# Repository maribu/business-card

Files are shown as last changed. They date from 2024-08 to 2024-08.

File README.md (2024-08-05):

# Marian's Business Card

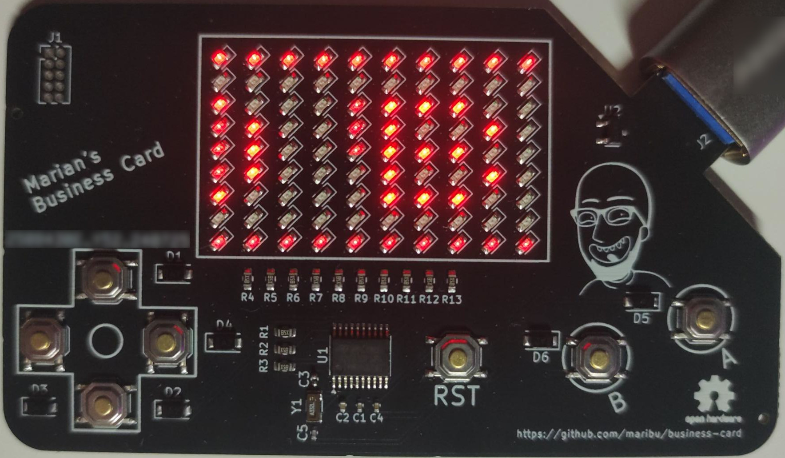
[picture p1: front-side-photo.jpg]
photo of the front side of the PCB

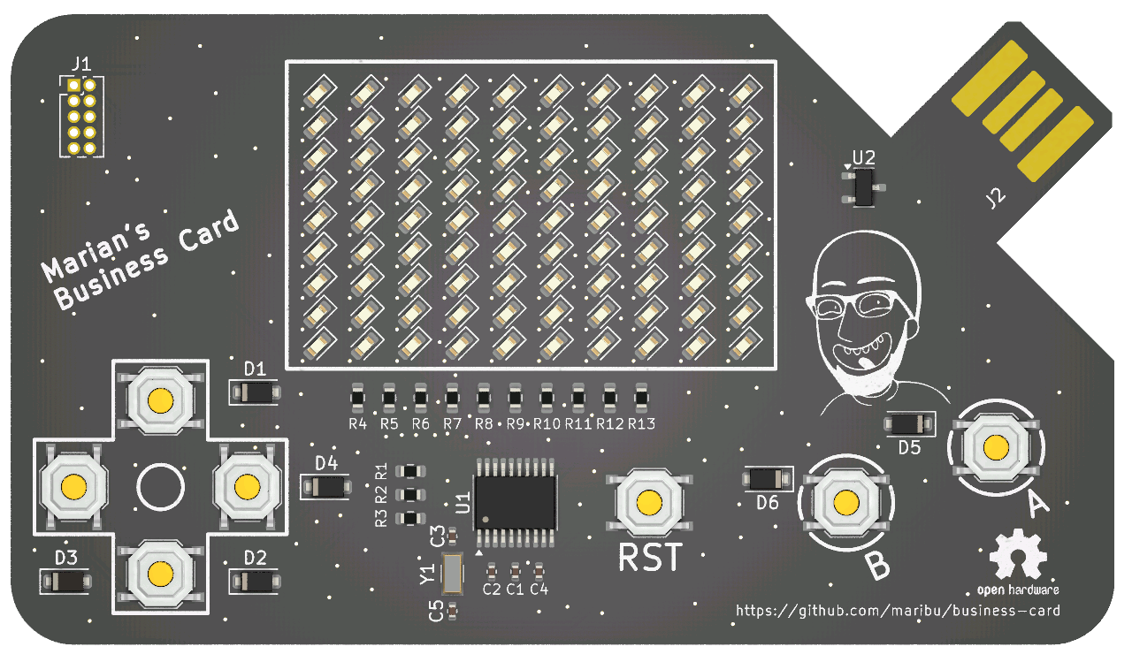
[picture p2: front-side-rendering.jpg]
rendering of the front side of the PCB


This repository contains an open hardware business card running open source
software.

## Getting started

### Hardware

Using KiCad, add Silkscreen details such as your name. E.g. I added my contact
details and word cloud of my skills on the back of the PCB. Using the JLCPCB
fabrication plugin of KiCAD, you can export the production files to directly
order the PCBs.

Note that when using vanilla PCB options (1.6 mm PCB thickness, HASL surface
finish) the USB connector will be a tad too thin to perfectly make contact with
a USB socket. Ideally you would use 2.0 mm PCB thickness and ENIG surface
finish, but that would be so expensive that it defeats the purpose of a
business card. Instead, you can just add a bit of solder on the USB contacts to
increase the thickness.

### Software

A simple "hello world" demo is given in
`software/RIOT-based-apps/apps/hello-world` that you can flash using e.g. a
J-Link EDU Mini programmer. Rather than using a cable, just plug the pins of
the J-Link EDU Mini programmer from the underside through the holes and rotate
the programmer until the pins and holes have contact. In addition, you need to
power the board (ideally via a USB-A extension cord).

With the programmer connected and the board powered, simply run:

    make flash

Refer to the [RIOT documentation](https://doc.riot-os.org/) for more details on
the software.

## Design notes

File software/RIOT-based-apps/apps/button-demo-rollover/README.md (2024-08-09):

# Button Rollover Demo

The use of Charlieplexing for has the disadvantage that when more than one
button is pressed at the same time, it may be impossible to reliably determine
which set of buttons is pressed.

E.g. the up button is detected when current can flow from `BUTTON_MATRIX_PIN_0`
to `BUTTON_MATRIX_PIN_2`, the right button is detected when current can flow
from `BUTTON_MATRIX_PIN_2` to `BUTTON_MATRIX_PIN_1`, and the left button is
detected when current can flow from `BUTTON_MATRIX_PIN_0` to
`BUTTON_MATRIX_PIN_1`. If now both the up and the right button are pressed,
current can flow from `BUTTON_MATRIX_PIN_0` to `BUTTON_MATRIX_PIN_2` (via the
closed up button) and from `BUTTON_MATRIX_PIN_2` to `BUTTON_MATRIX_PIN_1` (via
the closed right button). Hence, current can also flow from pin 0 to pin 1 (via
pin 2), regardless of whether the left button is pressed or not.

The board provides the `compensate_rollover()` function that can help here:
Under the assumption that at most two buttons are pressed at the same time,
when registering three pressed buttons the ghost key can be reliably determined.

This app showcases this by displaying the raw button input at the top of
the screen and the compensated one at the bottom. Note that when pressing
three buttons at the same time, this simple heuristic is not sufficient.

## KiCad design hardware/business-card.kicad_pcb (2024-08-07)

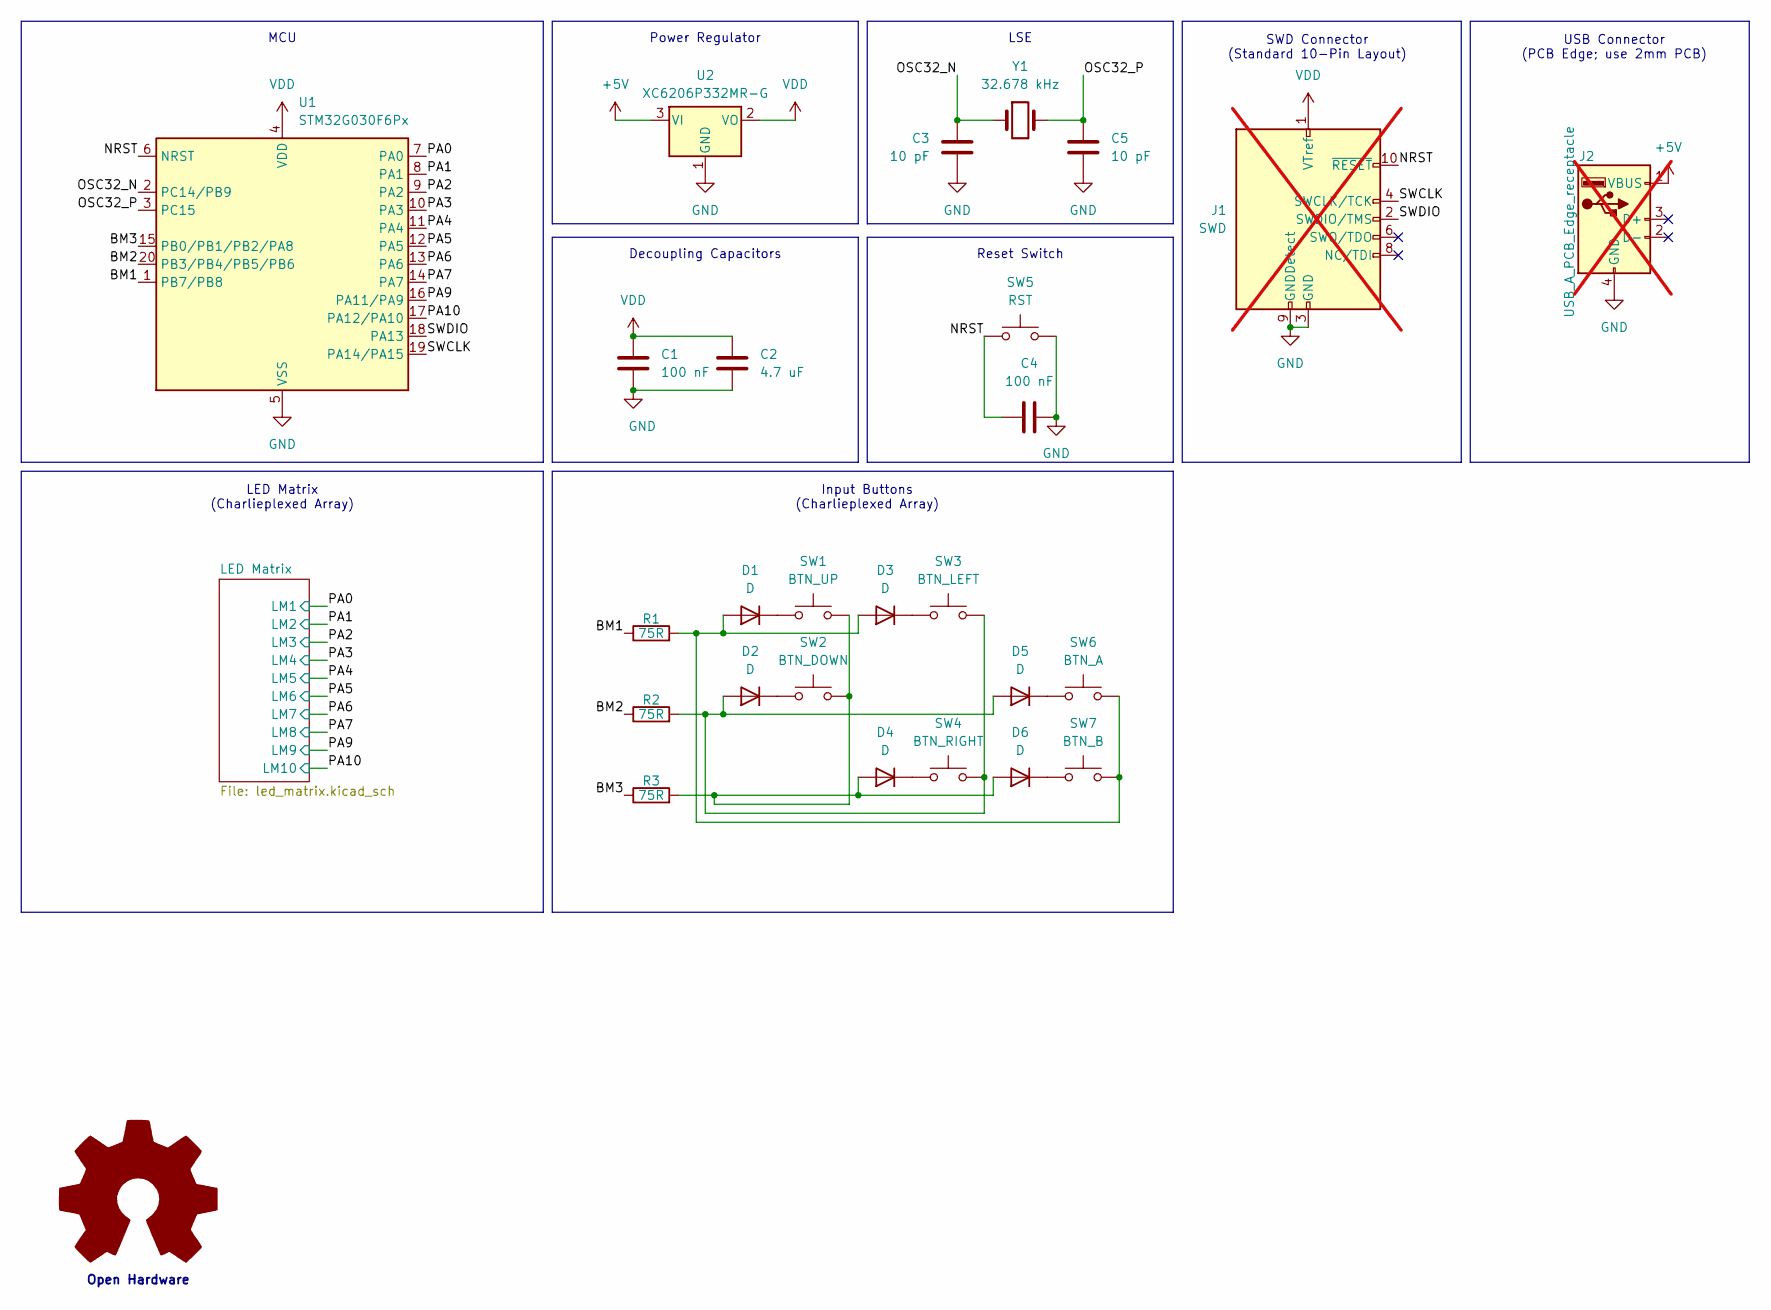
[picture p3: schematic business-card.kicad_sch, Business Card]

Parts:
C1, C4: 100 nF; C_0402_1005Metric; MPN C1525
C2: 4.7 uF; C_0402_1005Metric; MPN C23733
C3, C5: 10 pF; C_0402_1005Metric; MPN C32949
D1, D2, D3, D4, D5, D6: D; D_SOD-123F; MPN C64898
J1: SWD; PinHeader_2x05_P1.27mm_Vertical; not fitted
J2: USB_A_PCB_Edge_receptacle; not fitted
R1, R2, R3: 75R; R_0603_1608Metric; MPN C4275
SW1: BTN_UP; SW_Push_1P1T_XKB_TS-1187A; MPN C318884
SW2: BTN_DOWN; SW_Push_1P1T_XKB_TS-1187A; MPN C318884
SW3: BTN_LEFT; SW_Push_1P1T_XKB_TS-1187A; MPN C318884
SW4: BTN_RIGHT; SW_Push_1P1T_XKB_TS-1187A; MPN C318884
SW5: RST; SW_Push_1P1T_XKB_TS-1187A; MPN C318884
SW6: BTN_A; SW_Push_1P1T_XKB_TS-1187A; MPN C318884
SW7: BTN_B; SW_Push_1P1T_XKB_TS-1187A; MPN C318884
U1: STM32G030F6Px; TSSOP-20_4.4x6.5mm_P0.65mm; MPN C529330
U2: XC6206P332MR-G; SOT-23-3; MPN C5446
Y1: 32.678 kHz; Crystal_SMD_3215-2Pin_3.2x1.5mm; MPN C32346

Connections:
+5V: J2.1 (VBUS), U2.3 (VI)
/BM1: R1.1, U1.1 (PB7/PB8)
/BM2: R2.1, U1.20 (PB3/PB4/PB5/PB6)
/BM3: R3.1, U1.15 (PB0/PB1/PB2/PA8)
/NRST: C4.1, J1.10 (~RESET), SW5.1, U1.6 (NRST)
/OSC32_N: C3.1, U1.2 (PC14/PB9), Y1.1
/OSC32_P: C5.1, U1.3 (PC15), Y1.2
/PA0: U1.7 (PA0); also elsewhere on the board
/PA1: U1.8 (PA1); also elsewhere on the board
/PA2: U1.9 (PA2); also elsewhere on the board
/PA3: U1.10 (PA3); also elsewhere on the board
/PA4: U1.11 (PA4); also elsewhere on the board
/PA5: U1.12 (PA5); also elsewhere on the board
/PA6: U1.13 (PA6); also elsewhere on the board
/PA7: U1.14 (PA7); also elsewhere on the board
/PA9: U1.16 (PA11/PA9); also elsewhere on the board
/PA10: U1.17 (PA12/PA10); also elsewhere on the board
/SWCLK: J1.4 (SWCLK/TCK), U1.19 (PA14/PA15)
/SWDIO: J1.2 (SWDIO/TMS), U1.18 (PA13)
GND: C1.2, C2.2, C3.2, C4.2, C5.2, J1.3 (GND), J1.5 (GND), J1.9 (GNDDetect), J2.4 (GND), SW5.2, U1.5 (VSS), U2.1 (GND)
unnamed: D1.2 (A), D3.2 (A), R1.2, SW6.2, SW7.2
unnamed: D1.1 (K), SW1.1
unnamed: D2.2 (A), D5.2 (A), R2.2, SW3.2, SW4.2
unnamed: D2.1 (K), SW2.1
unnamed: D3.1 (K), SW3.1
unnamed: D4.2 (A), D6.2 (A), R3.2, SW1.2, SW2.2
unnamed: D4.1 (K), SW4.1
unnamed: D5.1 (K), SW6.1
unnamed: D6.1 (K), SW7.1
VDD: C1.1, C2.1, J1.1 (VTref), U1.4 (VDD), U2.2 (VO)

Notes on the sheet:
Input Buttons (Charlieplexed Array)
SWD Connector (Standard 10-Pin Layout)
MCU
Reset Switch
Power Regulator
LSE
Decoupling Capacitors
USB Connector (PCB Edge; use 2mm PCB)
LED Matrix (Charlieplexed Array)
Open Hardware

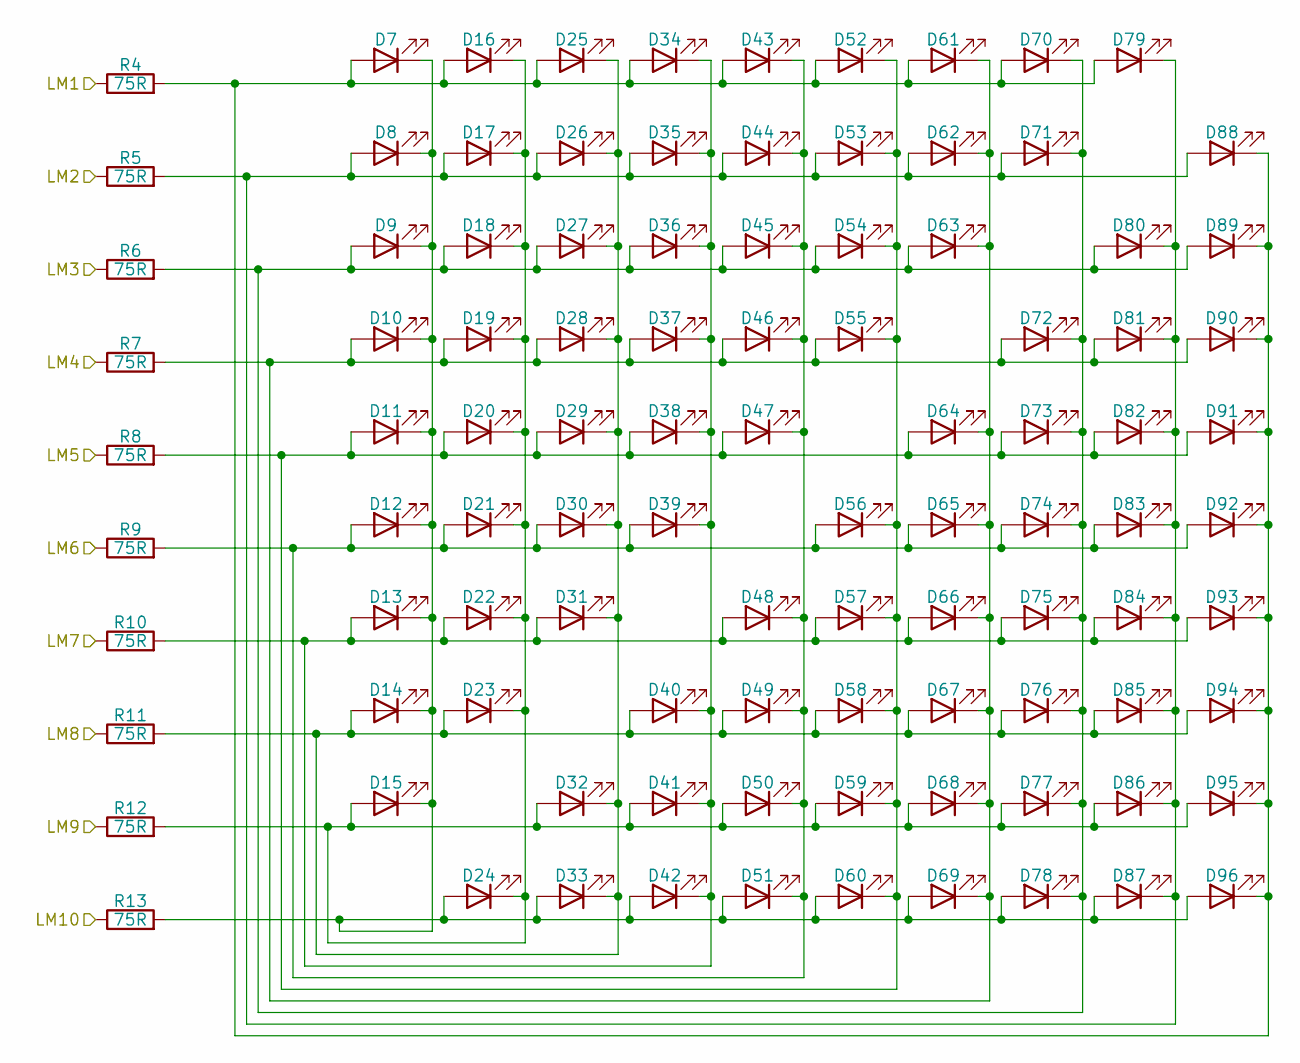
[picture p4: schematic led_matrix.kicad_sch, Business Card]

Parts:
D7, D8, D9, D10, D11, D12, D13, D14, D15, D16, D17, D18, D19, D20, D21, D22, D23, D24, D25, D26, D27, D28, D29, D30, D31, D32, D33, D34, D35, D36, D37, D38, D39, D40, D41, D42, D43, D44, D45, D46, D47, D48, D49, D50, D51, D52, D53, D54, D55, D56, D57, D58, D59, D60, D61, D62, D63, D64, D65, D66, D67, D68, D69, D70, D71, D72, D73, D74, D75, D76, D77, D78, D79, D80, D81, D82, D83, D84, D85, D86, D87, D88, D89, D90, D91, D92, D93, D94, D95, D96: LED; LED_0603_1608Metric; LCSC C2286
R4, R5, R6, R7, R8, R9, R10, R11, R12, R13: 75R; R_0603_1608Metric; LCSC C4275

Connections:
/PA0: R4.1; also elsewhere on the board
/PA1: R5.1; also elsewhere on the board
/PA2: R6.1; also elsewhere on the board
/PA3: R7.1; also elsewhere on the board
/PA4: R8.1; also elsewhere on the board
/PA5: R9.1; also elsewhere on the board
/PA6: R10.1; also elsewhere on the board
/PA7: R11.1; also elsewhere on the board
/PA9: R12.1; also elsewhere on the board
/PA10: R13.1; also elsewhere on the board
unnamed: D10.2 (A), D19.2 (A), D28.2 (A), D37.2 (A), D46.2 (A), D55.2 (A), D61.1 (K), D62.1 (K), D63.1 (K), D64.1 (K), D65.1 (K), D66.1 (K), D67.1 (K), D68.1 (K), D69.1 (K), D72.2 (A), D81.2 (A), D90.2 (A), R7.2
unnamed: D7.1 (K), D8.1 (K), D9.1 (K), D10.1 (K), D11.1 (K), D12.1 (K), D13.1 (K), D14.1 (K), D15.1 (K), D24.2 (A), D33.2 (A), D42.2 (A), D51.2 (A), D60.2 (A), D69.2 (A), D78.2 (A), D87.2 (A), D96.2 (A), R13.2
unnamed: D11.2 (A), D20.2 (A), D29.2 (A), D38.2 (A), D47.2 (A), D52.1 (K), D53.1 (K), D54.1 (K), D55.1 (K), D56.1 (K), D57.1 (K), D58.1 (K), D59.1 (K), D60.1 (K), D64.2 (A), D73.2 (A), D82.2 (A), D91.2 (A), R8.2
unnamed: D12.2 (A), D21.2 (A), D30.2 (A), D39.2 (A), D43.1 (K), D44.1 (K), D45.1 (K), D46.1 (K), D47.1 (K), D48.1 (K), D49.1 (K), D50.1 (K), D51.1 (K), D56.2 (A), D65.2 (A), D74.2 (A), D83.2 (A), D92.2 (A), R9.2
unnamed: D13.2 (A), D22.2 (A), D31.2 (A), D34.1 (K), D35.1 (K), D36.1 (K), D37.1 (K), D38.1 (K), D39.1 (K), D40.1 (K), D41.1 (K), D42.1 (K), D48.2 (A), D57.2 (A), D66.2 (A), D75.2 (A), D84.2 (A), D93.2 (A), R10.2
unnamed: D14.2 (A), D23.2 (A), D25.1 (K), D26.1 (K), D27.1 (K), D28.1 (K), D29.1 (K), D30.1 (K), D31.1 (K), D32.1 (K), D33.1 (K), D40.2 (A), D49.2 (A), D58.2 (A), D67.2 (A), D76.2 (A), D85.2 (A), D94.2 (A), R11.2
unnamed: D15.2 (A), D16.1 (K), D17.1 (K), D18.1 (K), D19.1 (K), D20.1 (K), D21.1 (K), D22.1 (K), D23.1 (K), D24.1 (K), D32.2 (A), D41.2 (A), D50.2 (A), D59.2 (A), D68.2 (A), D77.2 (A), D86.2 (A), D95.2 (A), R12.2
unnamed: D7.2 (A), D16.2 (A), D25.2 (A), D34.2 (A), D43.2 (A), D52.2 (A), D61.2 (A), D70.2 (A), D79.2 (A), D88.1 (K), D89.1 (K), D90.1 (K), D91.1 (K), D92.1 (K), D93.1 (K), D94.1 (K), D95.1 (K), D96.1 (K), R4.2
unnamed: D8.2 (A), D17.2 (A), D26.2 (A), D35.2 (A), D44.2 (A), D53.2 (A), D62.2 (A), D71.2 (A), D79.1 (K), D80.1 (K), D81.1 (K), D82.1 (K), D83.1 (K), D84.1 (K), D85.1 (K), D86.1 (K), D87.1 (K), D88.2 (A), R5.2
unnamed: D9.2 (A), D18.2 (A), D27.2 (A), D36.2 (A), D45.2 (A), D54.2 (A), D63.2 (A), D70.1 (K), D71.1 (K), D72.1 (K), D73.1 (K), D74.1 (K), D75.1 (K), D76.1 (K), D77.1 (K), D78.1 (K), D80.2 (A), D89.2 (A), R6.2

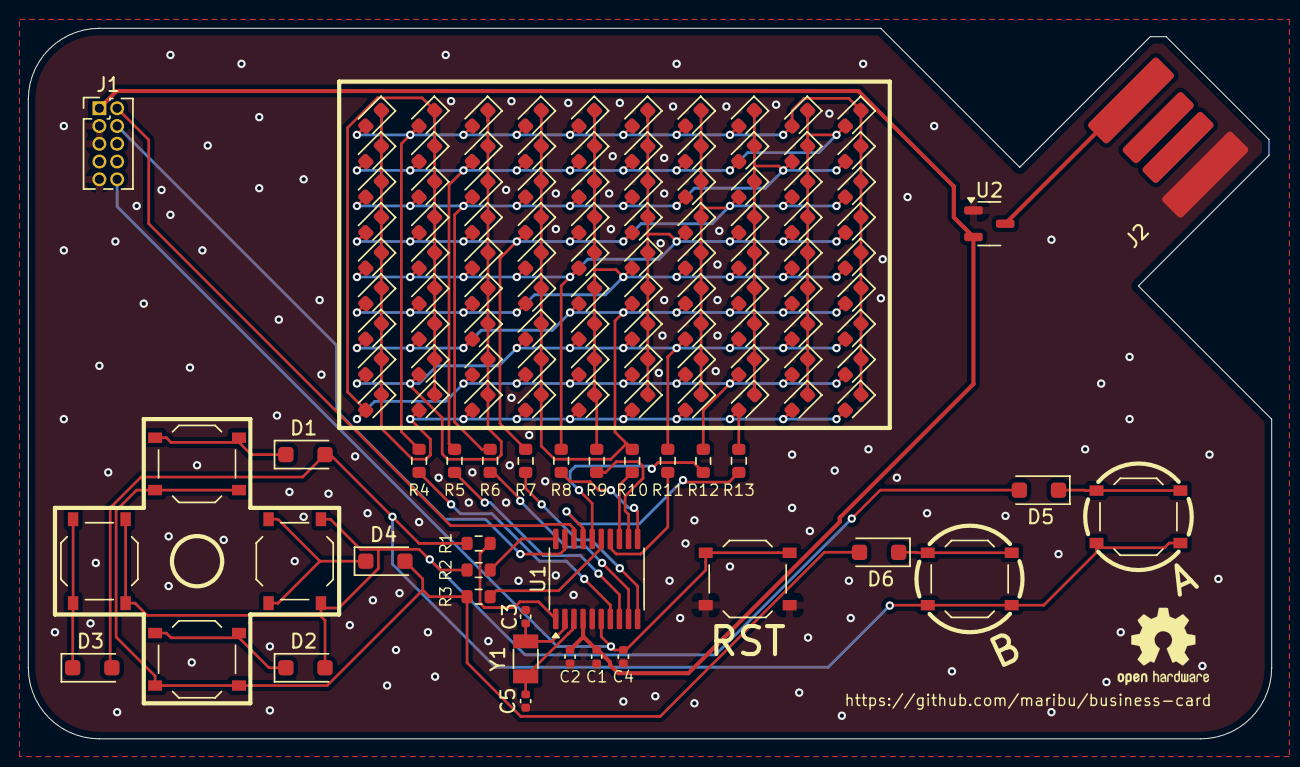
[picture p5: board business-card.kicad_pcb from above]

Board: 2 copper layers, 88.9 x 50.8 mm, 127 parts (0 on the bottom side), 40 nets.

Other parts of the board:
G**: OSHW-Logo2_7.3x6mm_SilkScreen

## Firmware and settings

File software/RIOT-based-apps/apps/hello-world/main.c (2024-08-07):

/*
 * Copyright (C) 2014 Freie Universität Berlin
 *
 * This file is subject to the terms and conditions of the GNU Lesser
 * General Public License v2.1. See the file LICENSE in the top level
 * directory for more details.
 */

/**
 * @ingroup     examples
 * @{
 *
 * @file
 * @brief       Hello World application
 *
 * @author      Kaspar Schleiser <kaspar@schleiser.de>
 * @author      Ludwig Knüpfer <ludwig.knuepfer@fu-berlin.de>
 *
 * @}
 */

#include <stdio.h>

#include "led_matrix.h"

int main(void)
{
    puts("Hello World!");

    printf("You are running RIOT on a(n) %s board.\n", RIOT_BOARD);
    printf("This board features a(n) %s CPU.\n", RIOT_CPU);

    const uint32_t frames_per_level = 2;
    uint32_t frame_target = led_matrix_frame_number() + frames_per_level;

    led_matrix_fb_clear();
    for (;;) {
        const char *text = "IoT";
        const size_t len = 3;

        for (uint8_t b = 1; b < LED_MATRIX_BRIGHTNESS_LEVELS; b++) {
            led_matrix_text(&bitmap_font_matrix_light8, text, len, 1, 1, b);
            frame_target = led_matrix_fb_switch(frame_target) + frames_per_level;
        }

        for (uint8_t b = LED_MATRIX_BRIGHTNESS_MAX; b > 0; b--) {
            led_matrix_text(&bitmap_font_matrix_light8, text, len, 1, 1, b);
            frame_target = led_matrix_fb_switch(frame_target) + frames_per_level;
        }
    }

    return 0;
}

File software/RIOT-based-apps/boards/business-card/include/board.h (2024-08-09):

/*
 * Copyright (C) 2024 Marian Buschsieweke
 *
 * This file is subject to the terms and conditions of the GNU Lesser
 * General Public License v2.1. See the file LICENSE in the top level
 * directory for more details.
 */

/**
 * @ingroup     boards_business_card
 * @{
 *
 * @file
 * @brief       Board specific definitions for Marian's Business Card
 *
 * @author      Marian Buschsieweke <marian.buschsieweke@posteo.net>
 */

#ifndef BOARD_H
#define BOARD_H

#include "cpu.h"
#include "periph_conf.h"
#include "periph_cpu.h"

#ifdef __cplusplus
extern "C" {
#endif

/**
 * @name Charlieplexed LED Matrix GPIOs
 * @{
 */
#define LED_MATRIX_TIMER        TIMER_DEV(0)    /**< Timer to use for updating the LED matrix */
#define LED_MATRIX_PORT         GPIO_PORT_A     /**< The GPIO port the LED matrix connected to */

#define LED_MATRIX_PIN_0        0               /**< GPIO pin number connected to LED matrix 0 */
#define LED_MATRIX_PIN_1        1               /**< GPIO pin number connected to LED matrix 1 */
#define LED_MATRIX_PIN_2        2               /**< GPIO pin number connected to LED matrix 2 */
#define LED_MATRIX_PIN_3        3               /**< GPIO pin number connected to LED matrix 3 */
#define LED_MATRIX_PIN_4        4               /**< GPIO pin number connected to LED matrix 4 */
#define LED_MATRIX_PIN_5        5               /**< GPIO pin number connected to LED matrix 5 */
#define LED_MATRIX_PIN_6        6               /**< GPIO pin number connected to LED matrix 6 */
#define LED_MATRIX_PIN_7        7               /**< GPIO pin number connected to LED matrix 7 */
#define LED_MATRIX_PIN_8        11              /**< GPIO pin number connected to LED matrix 8 */
#define LED_MATRIX_PIN_9        12              /**< GPIO pin number connected to LED matrix 9 */
/** @} */

/**
 * @name Charlieplexed Button Matrix GPIOs
 * @{
 */
#define BUTTON_MATRIX_PORT              GPIO_PORT_B     /**< The GPIO port the button matrix connected to */

#define BUTTON_MATRIX_PIN_0             7               /**< GPIO pin number of button matrix pin 0 */
#define BUTTON_MATRIX_PIN_1             4               /**< GPIO pin number of button matrix pin 1 */
#define BUTTON_MATRIX_PIN_2             0               /**< GPIO pin number of button matrix pin 2 */

/* for button_matrix_test() */
#define BUTTON_MATRIX_COORD_UP          0,0     /**< Button matrix coordinates of the up button */
#define BUTTON_MATRIX_COORD_DOWN        0,1     /**< Button matrix coordinates of the up button */
#define BUTTON_MATRIX_COORD_LEFT        1,0     /**< Button matrix coordinates of the left button */
#define BUTTON_MATRIX_COORD_RIGHT       1,2     /**< Button matrix coordinates of the right button */
#define BUTTON_MATRIX_COORD_A           2,1     /**< Button matrix coordinates of the "A" button */
#define BUTTON_MATRIX_COORD_B           2,2     /**< Button matrix coordinates of the "B" button */

/* for button_matrix_scan() */
#define BUTTON_UP       0x01    /**< Bitmask to check for the up button */
#define BUTTON_LEFT     0x02    /**< Bitmask to check for the left button */
#define BUTTON_DOWN     0x04    /**< Bitmask to check for the down button */
#define BUTTON_A        0x08    /**< Bitmask to check for the "A" button */
#define BUTTON_RIGHT    0x10    /**< Bitmask to check for the right button */
#define BUTTON_B        0x20    /**< Bitmask to check for the "B" button */

/**
 * @brief   Heuristic to filter out fake inputs due to rollover
 *
 * The currently implemented heuristic assumes that at most two buttons are
 * pressed at the same time. E.g. pressing both up and right button will
 * result in a ghost reading for button left. So when up, right, and left
 * are enabled, it will assume that in fact only up and right are pressed
 * and left is a ghost input, which is trimmed.
 *
 * As long as indeed only two buttons are pressed at the same time, this
 * simple heuristic is sufficient. More sophisticated heuristics are
 * certainly possible that e.g. track the state over time. But
 * 2-key-rollover seems to be good enough for most games.
 *
 * @param[in]   scan    The output of button_matrix_scan()
 * @returl  The bitmask without rollover artifacts
 */
uint8_t compensate_rollover(uint8_t scan);
/** @} */

#ifdef __cplusplus
}
#endif

#endif /* BOARD_H */
/** @} */

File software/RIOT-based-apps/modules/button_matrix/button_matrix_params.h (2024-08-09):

/*
 * Copyright (C) 2024 Marian Buschsieweke
 *
 * This file is subject to the terms and conditions of the GNU Lesser
 * General Public License v2.1. See the file LICENSE in the top level
 * directory for more details.
 */

/**
 * @ingroup     drivers_button_matrix
 * @{
 *
 * @file
 * @brief       Hardware parameters of the button matrix
 *
 * @author      Marian Buschsieweke <marian.buschsieweke@posteo.net>
 */

#ifndef BUTTON_MATRIX_PARAMS_H
#define BUTTON_MATRIX_PARAMS_H

#include "board.h"

#ifdef __cplusplus
extern "C" {
#endif

#ifndef BUTTON_MATRIX_PORT
#  error "BUTTON_MATRIX_PORT not defined"
#endif

/**
 * @brief   Pin numbers of the button matrix
 */
static const uint8_t button_matrix_pins[] = {
    BUTTON_MATRIX_PIN_0,
    BUTTON_MATRIX_PIN_1,
#ifdef BUTTON_MATRIX_PIN_2
    BUTTON_MATRIX_PIN_2,
#endif
#ifdef BUTTON_MATRIX_PIN_3
    BUTTON_MATRIX_PIN_3,
#endif
#ifdef BUTTON_MATRIX_PIN_4
    BUTTON_MATRIX_PIN_4,
#endif
#ifdef BUTTON_MATRIX_PIN_5
    BUTTON_MATRIX_PIN_5,
#endif
#ifdef BUTTON_MATRIX_PIN_6
    BUTTON_MATRIX_PIN_6,
#endif
#ifdef BUTTON_MATRIX_PIN_7
    BUTTON_MATRIX_PIN_7,
#endif
#ifdef BUTTON_MATRIX_PIN_8
    BUTTON_MATRIX_PIN_8,
#endif
#ifdef BUTTON_MATRIX_PIN_9
    BUTTON_MATRIX_PIN_9,
#endif
#ifdef BUTTON_MATRIX_PIN_10
    BUTTON_MATRIX_PIN_10,
#endif
#ifdef BUTTON_MATRIX_PIN_11
    BUTTON_MATRIX_PIN_11,
#endif
#ifdef BUTTON_MATRIX_PIN_12
    BUTTON_MATRIX_PIN_12,
#endif
#ifdef BUTTON_MATRIX_PIN_13
    BUTTON_MATRIX_PIN_13,
#endif
#ifdef BUTTON_MATRIX_PIN_14
    BUTTON_MATRIX_PIN_14,
#endif
#ifdef BUTTON_MATRIX_PIN_15
    BUTTON_MATRIX_PIN_15,
#endif
};

#define BUTTON_MATRIX_PIN_NUMOF     ARRAY_SIZE(button_matrix_pins)  /**< Number of BUTTON matrix pins */
#define BUTTON_MATRIX_WIDTH         BUTTON_MATRIX_PIN_NUMOF         /**< Width of the BUTTON matrix */
#define BUTTON_MATRIX_HEIGHT        BUTTON_MATRIX_PIN_NUMOF         /**< Height of the BUTTON matrix */

/**
 * @brief   Number of BUTTONs in the matrix
 */
#define BUTTON_MATRIX_BUTTON_NUMOF  (BUTTON_MATRIX_WIDTH * (BUTTON_MATRIX_HEIGHT - 1))

#ifdef __cplusplus
}
#endif

#endif /* BUTTON_MATRIX_PARAMS_H */
/** @} */

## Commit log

2024-08-04 hardware: Add initial business card PCB
    [business-card.kicad_pcb, business-card.kicad_sch, led_matrix.kicad_sch]
2024-08-07 software/RIOT*: greatly improved font rendering
    This adds a new font from the https://github.com/trip5/Matrix-Fonts
    repository and a new binary font encoding that better fits
    fonts with variable width.
    The led_matrix module has been updated to allow specifying the
    font used to render text and the API has been improved.
    A simple heuristic to detect when adding a blank column between
    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
2024-08-07 hardware: Consistent label numbering
    Number the button matrix labels from top to bottom to match the
    numbering of the LED matrix.
    The labels on the MCU pins have been changed accordingly, so that
    this change is a no-op.
    The PCB has been updated accordingly, but other than netlist names
    nothing has changed.
    [business-card.kicad_pcb, business-card.kicad_sch]
2024-08-07 software/RIOT*/board: update button matrix names
    Match the numbering scheme from the schematic in the board
    file.
2024-08-09 software/RIOT*/modules/led_matrix: Improve doc
2024-08-09 software/RIOT*: Update RIOT submodule to current master
    The PR implementing gpio_ll_switch_dir for STM32 has been
    merged upstream.
2024-08-09 software/RIOT*: Add module to read out button matrix
    This adds a module to read out the button matrix and two
    demo apps. One works when at most one key is pressed at
    any point in time. The other uses a simple heuristic to
    provide 2-key-rollover input.
